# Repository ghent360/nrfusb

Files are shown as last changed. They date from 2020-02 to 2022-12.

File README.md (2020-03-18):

# Theory of operation #

A transmitter and receiver must be programmed with identical 32 bit
radio IDs.  With those IDs, the transmitter and receiver select a set of
23 channels using a pseudorandom number generator.

## Channel Selection ##

23 channels are selected.  Their selection and order is determined as
follows:

The pseudorandom number function is:

```
prn = (prn * 0x0019660D) + 0x3C6EF35F
```

A potential channel is `prn % 125`.  Channels are evaluated in order such that:

* The prn is evaluated once, then modulo 125 to generate a candidate
  channel

* No channel is repeated.  If the candidate channel has already been
  selected, the candidate is discarded.

* No more than a certain number of channels can be chosen from each of
  the different bands.  If a candidate channel would exceed this
  limit, it is discarded.
  * 0-31: 6
  * 32-63: 6
  * 64-95: 6
  * 96-125: 5

## Transmission ##

The transmitter and receiver use the nrf24l01 Enhanced ShockBurst with
the following parameters:

* 5 byte address field, the channel ID mapped into 5 bytes as below
* Dynamic payload length
* 2 byte CRC
* No automatic retransmission
* Auto acknowledgement
* 1Mbps data rate

The transmitter sends a new packet every 20ms, waiting 1ms for an
acknowledgement with data on the same channel.  Each transmitted
packet advances to the next channel in the channel selected list,
wrapping around.

## Reception ##

To initially lock onto a transmitter, the receiver picks a random
channel from the list and listens for 20 channel change times (0.4s).
If no packet is received, it then moves to the next channel in the
list and waits another 20 time periods, continuing this process until
a packet is received.  Once a packet is received it switches to the
following procedure.

In normal reception, immediately after receiving and acknowledging a
packet, the receiver switches to the next channel in the list.  It
waits at least 22ms for the next packet to be received.  If no packet
is received, then the channel is switched to the next one and
listening recommences.  If 5 packets in a row are missed, then the
receiver returns to the initial lock procedure.

## ID selection ##

The ShockBurst address is derived from the 32 bit ID as follows.

1100bbbb bbbbbbbH bbbbbbbH bbbbbbbH bbbbbbH

`b` is a bit from the 32 bit ID.

The `H` bits are selected to be the opposite of whatever the
preceeding bit was.

Rationale: The highest bits are defined to be distinct from the
preamble, which consists of alternating bits.  The H bits are present
to reduce the likelihood that random noise will cause the address to
be identified by the baseband receiver.

## Scheduling ##

The transmitter and receiver have 15 different "slots" to hold
outgoing data.  Each can be configured for a different priority or
transmission rate and each can hold up to 16 bytes of data.

The transmission rate/priority is configured by providing a 32 bit
bitmask denoting in which timeslots this slot should be sent.
Configuring an infeasible set of slots will result in unspecified data
being sent at a lower rate.

A priority of 0 is the default, which signifies that the slot should
not be transmitted.  0xffffffff implies it should be sent every
timeslot.  0x55555555 would be every other timeslot, etc.

The data in a slot will continue to be transmitted at the specified
frequency whether or not it has been updated by the client recently.

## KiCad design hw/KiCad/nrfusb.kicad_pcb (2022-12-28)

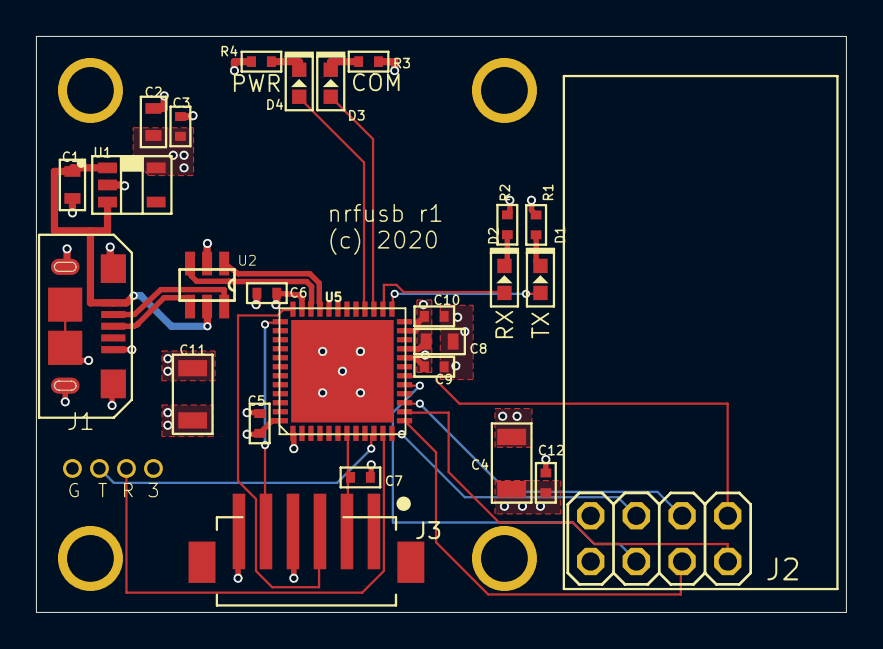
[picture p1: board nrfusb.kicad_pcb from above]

Board: 4 copper layers, 45.0 x 32.0 mm, 34 parts (0 on the bottom side), 26 nets.

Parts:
C1, C2, C8: 1uF; C0603
C3, C5, C6, C7, C9, C10, C12: 0.1uF; C0402
C4, C11: 10uF; C1206
D1, D3: MF-LED-0603-GREEN; LED0603
D2, D4: MF-LED-0603-RED; LED0603
D3V0: PAD24AWG_PAD; 24AWG_PAD
DGND0: PAD24AWG_PAD; 24AWG_PAD
DRX0: PAD24AWG_PAD; 24AWG_PAD
DTX0: PAD24AWG_PAD; 24AWG_PAD
J1: MF-CON-MICROUSB-RIGHT; MICROUSB-RIGHT
J2: 2X04
J3: JST-ZH6SMT_VERT; JST_B6B-ZR-SM4-TF(LF)(SN)
M1, M2, M3, M4: MOUNT; M2.5MOUNT
R1, R2, R3, R4: 220; R0402
U1: MF-REG-SOT235-3.3V-300mA; SOT-23-5
U2: USBLC6-2SC6; SOT23-6L
U5: STM32G474CEU6; QFN50P700X700X60-49N

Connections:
+3V3: C2.P$1, C3.P$1, C4.P$1, C5.P$1, C6.P$1, C8.P$1, C9.P$1, C10.P$1, C11.P$1, C12.P$1, D3V0.P$1, J2.7, J3.6, U1.P$5, U5.1, U5.20, U5.21, U5.23, U5.35, U5.48
DEBUG_RX: DRX0.P$1, U5.11
DEBUG_TX: DTX0.P$1, U5.10
GND: C1.P$2, C2.P$2, C3.P$2, C4.P$2, C5.P$2, C6.P$2, C7.P$2, C8.P$2, C9.P$2, C10.P$2, C11.P$2, C12.P$2, DGND0.P$1, J1.5, J1.S1, J1.S2, J1.S3, J1.S4, J1.S5, J1.S6, J2.8, J3.4, R1.P$1, R2.P$1, R3.P$1, R4.P$1, U1.P$2, U2.2, U5.49
LED_COM: D3.ANODE, U5.27
LED_PWR: D4.ANODE, U5.28
LED_RF_RX: D2.ANODE, U5.26
LED_RF_TX: D1.ANODE, U5.25
unnamed: D1.CATHODE, R1.P$2
unnamed: D2.CATHODE, R2.P$2
unnamed: D3.CATHODE, R3.P$2
unnamed: D4.CATHODE, R4.P$2
NRF_CE: J2.6, U5.17
NRF_CS: J2.5, U5.12
NRF_IRQ: J2.1, U5.18
NRF_MISO: J2.2, U5.14
NRF_MOSI: J2.3, U5.15
NRF_SCK: J2.4, U5.13
NRST: C7.P$1, J3.2, U5.7
SWCLK: J3.5, U5.37
SWDIO: J3.3, U5.36
USB_D_N: J1.2, U2.6
USB_D_P: J1.3, U2.4
USB_F_N: U2.1, U5.33
USB_F_P: U2.3, U5.34
VBUS: C1.P$1, J1.1, U1.P$1, U1.P$3, U2.5

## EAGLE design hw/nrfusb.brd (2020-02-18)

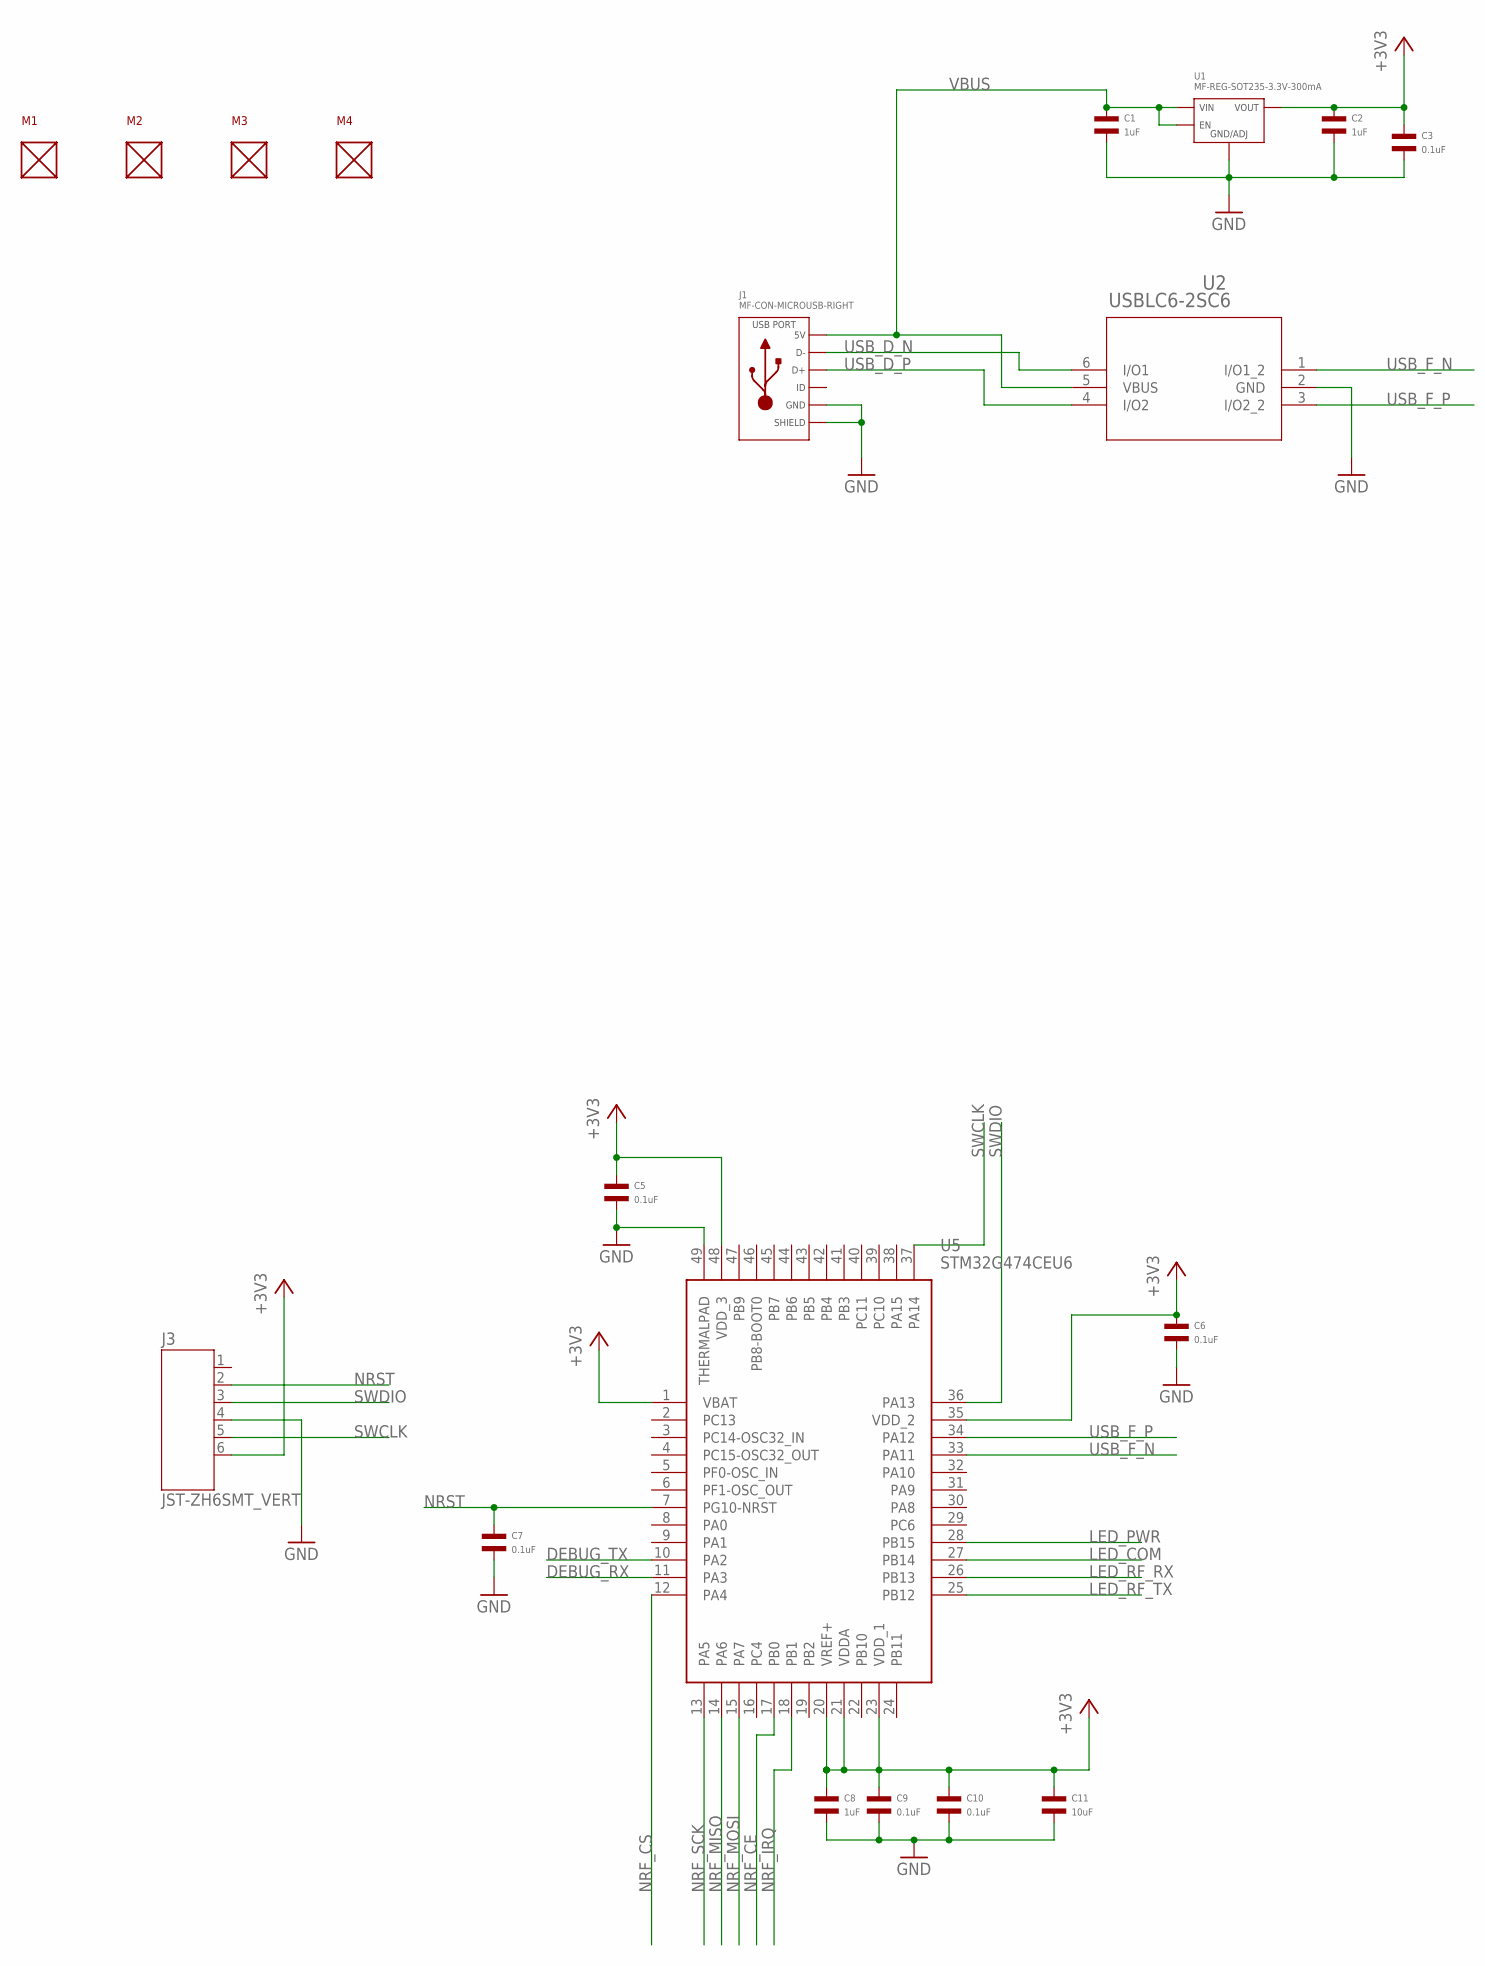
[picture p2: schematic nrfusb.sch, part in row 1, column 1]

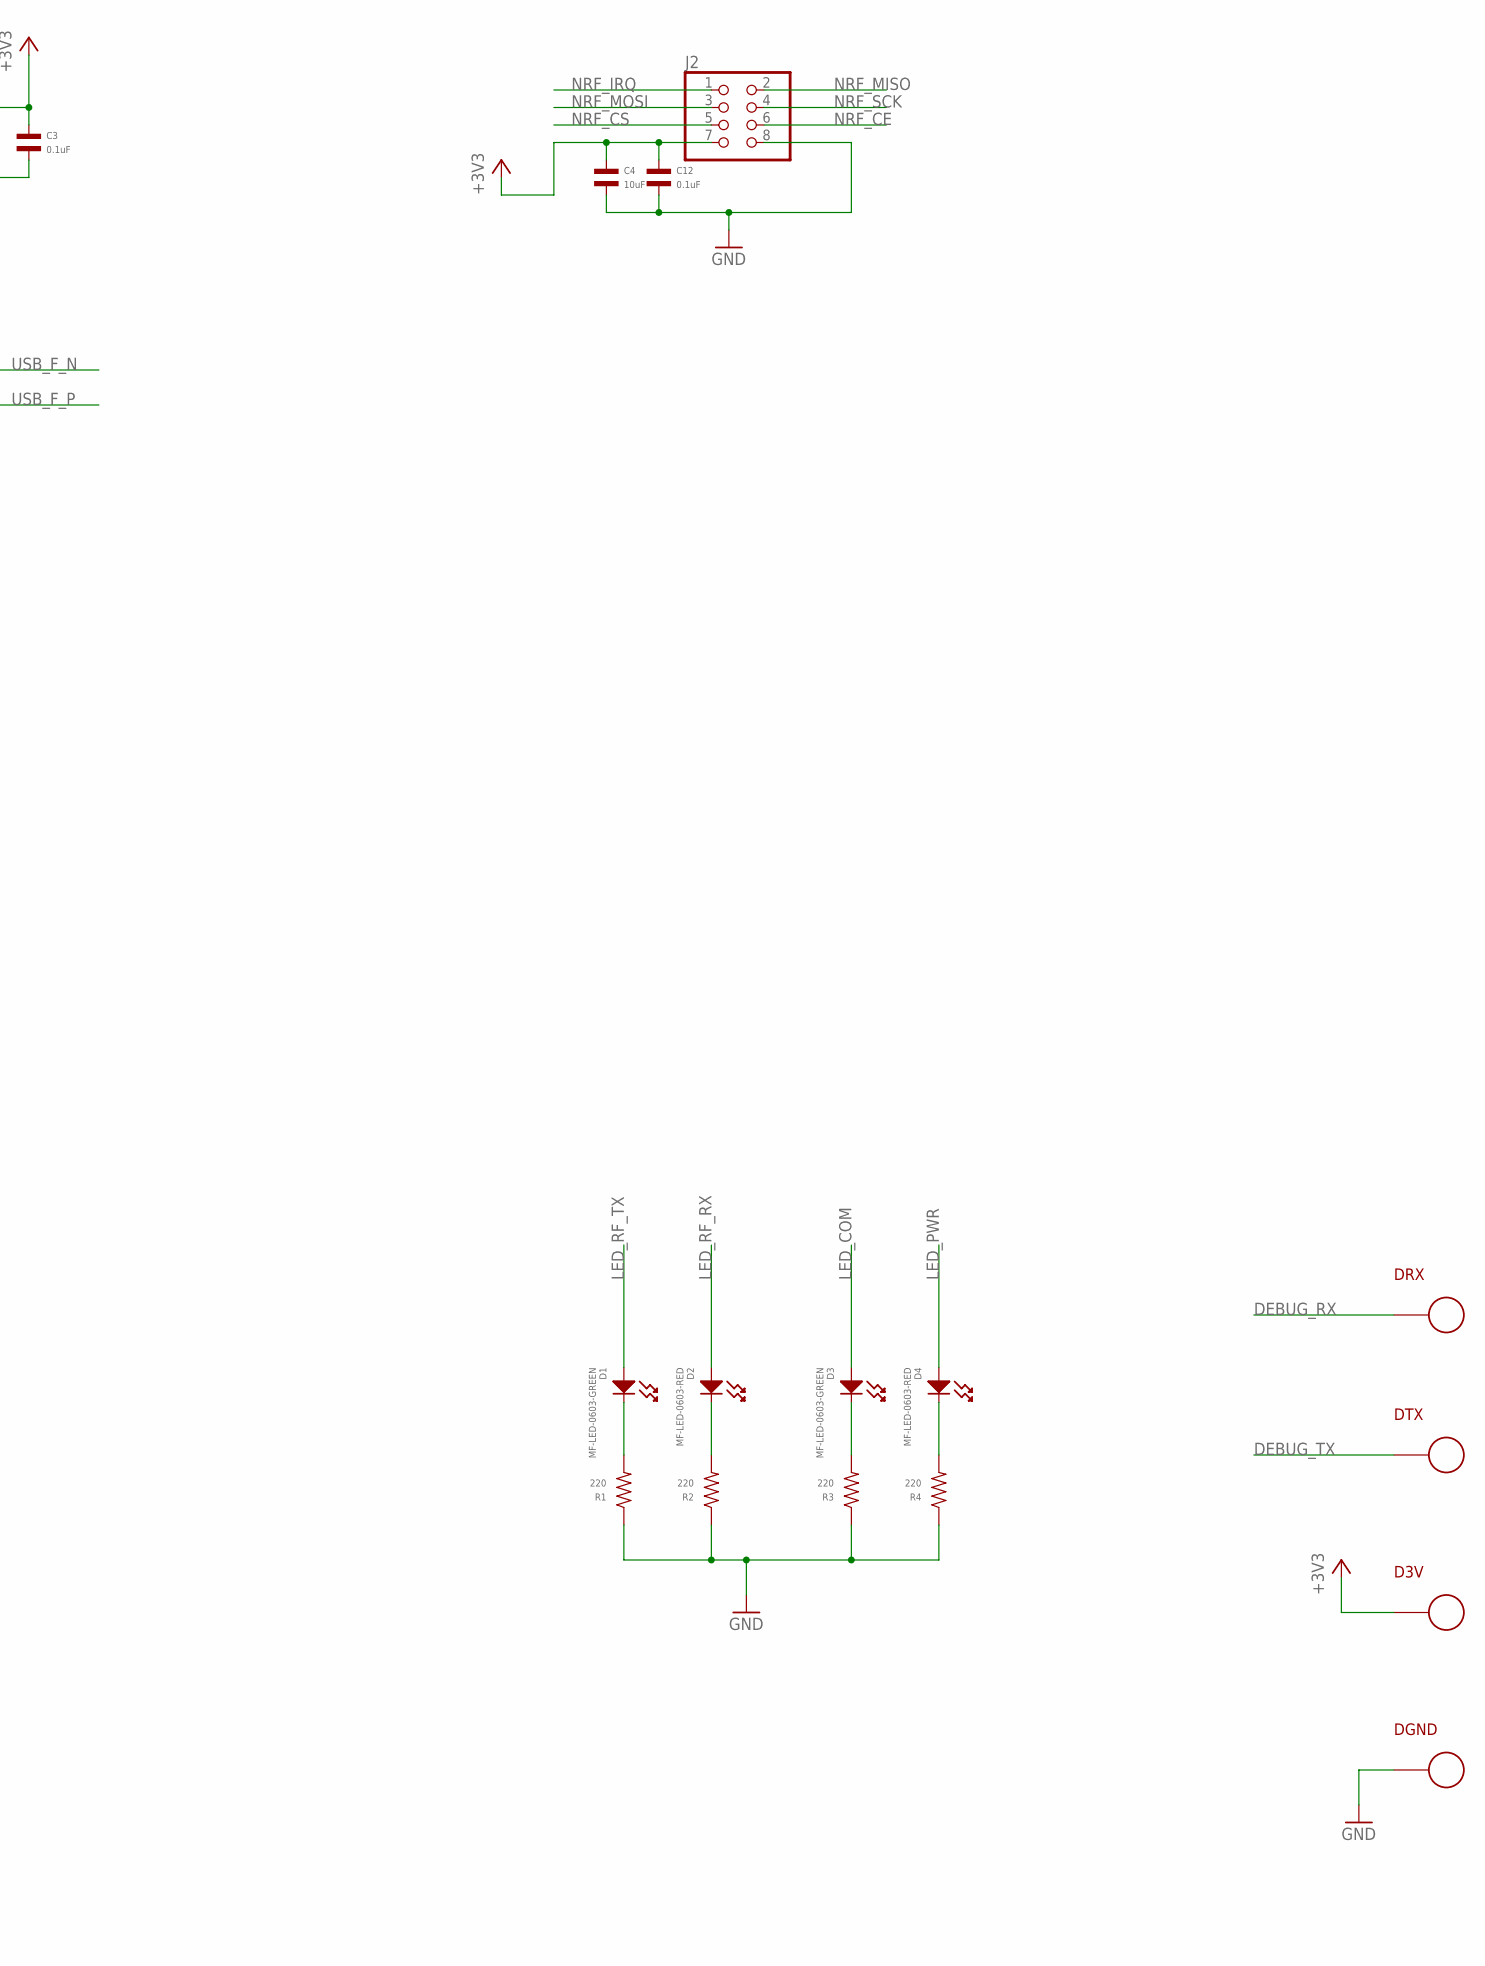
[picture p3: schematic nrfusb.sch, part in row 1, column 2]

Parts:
C1, C2, C8: 1uF; C0603; MPN MF-CAP-0603-1uF
C3, C5, C6, C7, C9, C10, C12: 0.1uF; C0402; MPN MF-CAP-0402-0.1uF
C4, C11: 10uF; C1206; MPN MF-CAP-1206-10uF
D1, D3: MF-LED-0603-GREEN; LED0603
D2, D4: MF-LED-0603-RED; LED0603
D3V: PAD24AWG_PAD; 24AWG_PAD
DGND: PAD24AWG_PAD; 24AWG_PAD
DRX: PAD24AWG_PAD; 24AWG_PAD
DTX: PAD24AWG_PAD; 24AWG_PAD
J1: MF-CON-MICROUSB-RIGHT; MICROUSB-RIGHT
J2: PINHD-2X4; 2X04; MPN 61300821121
J3: JST-ZH6SMT_VERT; JST_B6B-ZR-SM4-TF(LF)(SN); MPN B6B-ZR-SM4-TF(LF)(SN)
M1, M2, M3, M4: MOUNT; M2.5MOUNT
R1, R2, R3, R4: 220; R0402; MPN MF-RES-0402-220
U1: MF-REG-SOT235-3.3V-300mA; SOT-23-5
U2: USBLC6-2SC6; SOT23-6L; MPN USBLC6-2SC6
U5: STM32G474CEU6; QFN50P700X700X60-49N; MPN STM32G474CEU6

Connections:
+3V3: C2.P$1, C3.P$1, C4.P$1, C5.P$1, C6.P$1, C8.P$1, C9.P$1, C10.P$1, C11.P$1, C12.P$1, D3V.P$1, J2.7, J3.6, U1.P$5 (VOUT), U5.1 (VBAT), U5.20 (VREF+), U5.21 (VDDA), U5.23 (VDD_1), U5.35 (VDD_2), U5.48 (VDD_3)
DEBUG_RX: DRX.P$1, U5.11 (PA3)
DEBUG_TX: DTX.P$1, U5.10 (PA2)
GND: C1.P$2, C2.P$2, C3.P$2, C4.P$2, C5.P$2, C6.P$2, C7.P$2, C8.P$2, C9.P$2, C10.P$2, C11.P$2, C12.P$2, DGND.P$1, J1.5 (GND), J1.S1 (SLD), J1.S2 (SLD), J1.S3 (SLD), J1.S4 (SLD), J1.S5 (SLD), J1.S6 (SLD), J2.8, J3.4, R1.P$1, R2.P$1, R3.P$1, R4.P$1, U1.P$2 (GND/ADJ), U2.2 (GND), U5.49 (THERMALPAD)
LED_COM: D3.ANODE, U5.27 (PB14)
LED_PWR: D4.ANODE, U5.28 (PB15)
LED_RF_RX: D2.ANODE, U5.26 (PB13)
LED_RF_TX: D1.ANODE, U5.25 (PB12)
unnamed: D1.CATHODE, R1.P$2
unnamed: D2.CATHODE, R2.P$2
unnamed: D3.CATHODE, R3.P$2
unnamed: D4.CATHODE, R4.P$2
NRF_CE: J2.6, U5.17 (PB0)
NRF_CS: J2.5, U5.12 (PA4)
NRF_IRQ: J2.1, U5.18 (PB1)
NRF_MISO: J2.2, U5.14 (PA6)
NRF_MOSI: J2.3, U5.15 (PA7)
NRF_SCK: J2.4, U5.13 (PA5)
NRST: C7.P$1, J3.2, U5.7 (PG10-NRST)
SWCLK: J3.5, U5.37 (PA14)
SWDIO: J3.3, U5.36 (PA13)
USB_D_N: J1.2 (D-), U2.6 (I/O1)
USB_D_P: J1.3 (D+), U2.4 (I/O2)
USB_F_N: U2.1 (I/O1_2), U5.33 (PA11)
USB_F_P: U2.3 (I/O2_2), U5.34 (PA12)
VBUS: C1.P$1, J1.1 (5V), U1.P$1 (VIN), U1.P$3 (EN), U2.5 (VBUS)

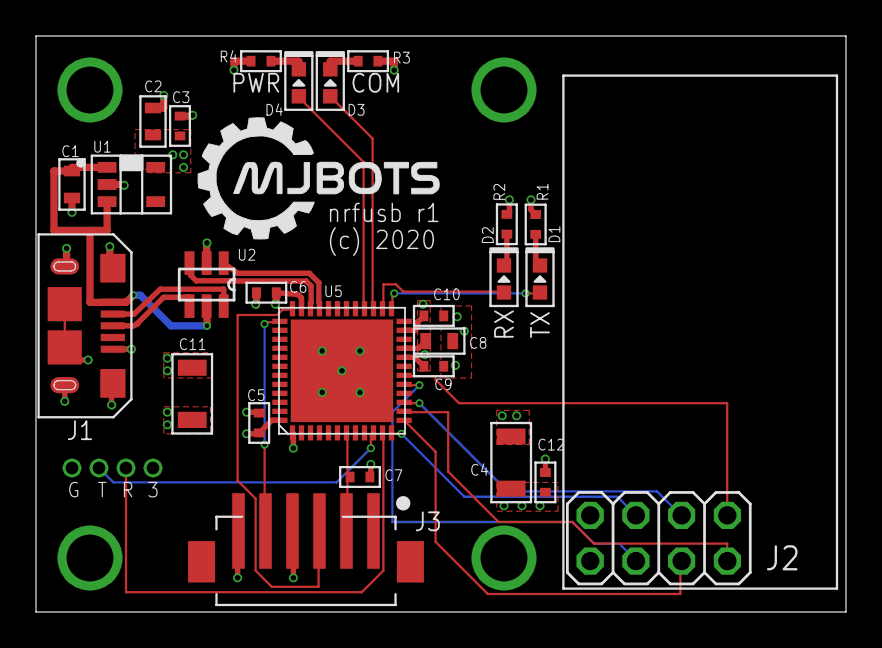
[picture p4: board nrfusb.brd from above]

Board: 4 copper layers, 45.0 x 32.0 mm, 34 parts (0 on the bottom side), 26 nets.

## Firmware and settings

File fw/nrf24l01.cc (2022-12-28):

// Copyright 2020 Josh Pieper, jjp@pobox.com.
//
// Licensed under the Apache License, Version 2.0 (the "License");
// you may not use this file except in compliance with the License.
// You may obtain a copy of the License at
//
//     http://www.apache.org/licenses/LICENSE-2.0
//
// Unless required by applicable law or agreed to in writing, software
// distributed under the License is distributed on an "AS IS" BASIS,
// WITHOUT WARRANTIES OR CONDITIONS OF ANY KIND, either express or implied.
// See the License for the specific language governing permissions and
// limitations under the License.

#include "fw/nrf24l01.h"

#include "mjlib/base/string_span.h"

namespace fw {

Nrf24l01::SpiMaster::SpiMaster(SPI* spi, PinName cs, MillisecondTimer* timer)
    : spi_(spi), cs_(cs, 1), timer_(timer) {
}

uint8_t Nrf24l01::SpiMaster::Command(
    uint8_t command,
    std::string_view data_in,
    mjlib::base::string_span data_out) {
  cs_.write(0);

  // The nrf24l01 has a 38ns CS setup time.  8 nops should get us
  // that for any stm32 frequency.
  asm("nop");
  asm("nop");
  asm("nop");
  asm("nop");
  asm("nop");
  asm("nop");
  asm("nop");
  asm("nop");

  const uint8_t status = spi_->write(command);

  const auto to_transfer =
      std::max<std::size_t>(data_in.size(), data_out.size());
  for (size_t i = 0; i < to_transfer; i++) {
    const uint8_t out_byte = spi_->write(
        (i < data_in.size()) ? data_in[i] : 0);
    if (i < static_cast<std::size_t>(data_out.size())) {
      data_out[i] = out_byte;
    }
  }

  cs_.write(1);

  return status;
}

uint8_t Nrf24l01::SpiMaster::WriteRegister(uint8_t address, std::string_view data) {
  return Command(0x20 + address, data, {});
}

uint8_t Nrf24l01::SpiMaster::WriteRegister(uint8_t address, uint8_t data) {
  return WriteRegister(address, {reinterpret_cast<const char*>(&data), 1});
}

uint8_t Nrf24l01::SpiMaster::ReadRegister(
    uint8_t address, mjlib::base::string_span data) {
  return Command(0x00 + address, {}, data);
}

uint8_t Nrf24l01::SpiMaster::ReadRegister(uint8_t address) {
  uint8_t result = 0;
  ReadRegister(address, {reinterpret_cast<char*>(&result), 1});
  return result;
}

bool Nrf24l01::SpiMaster::VerifyRegister(uint8_t address, std::string_view data) {
  constexpr int kMaxRetries = 2;

  for (int i = 0; i < kMaxRetries; i++) {
    WriteRegister(address, data);
    ReadRegister(address, {buf_, static_cast<ssize_t>(data.size())});
    if (data == std::string_view{buf_, data.size()}) {
      return true;
    }
  }

  // Well, we failed.  Report an error.
  return false;
}

bool Nrf24l01::SpiMaster::VerifyRegister(uint8_t address, uint8_t value) {
  return VerifyRegister(address, {reinterpret_cast<const char*>(&value), 1});
}

Nrf24l01::Nrf24l01(MillisecondTimer* timer, const Options& options)
    : timer_(timer),
      options_(options),
      spi_(options.pins.mosi, options.pins.miso, options.pins.sck),
      nrf_(&spi_, options.pins.cs, timer),
      irq_(options.pins.irq),
      ce_(options.pins.ce, 0) {
  spi_.frequency(10000000);
}

Nrf24l01::~Nrf24l01() {}

void Nrf24l01::Poll() {
  if (irq_.read() == 0) {
    // We have some interrupt to deal with.  Read the status.
    const uint8_t status = nrf_.Command(0xff, {}, {});

    if (status & (1 << 6)) {
      ReadPacket();

      if (is_data_ready_) { rx_overflow_ = true; }
      is_data_ready_ = true;
    }
    if (status & (1 << 4)) {
      // Retransmit count exceeded!
      retransmit_exceeded_++;

      // Flush our TX FIFO.
      nrf_.Command(0xe1, {}, {});
    }

    const uint8_t maybe_to_clear = status & 0x70;
    if (maybe_to_clear) {
      // Yes!
      nrf_.WriteRegister(0x07, maybe_to_clear);
    }
  }
}

void Nrf24l01::PollMillisecond() {
  const auto now = timer_->read_ms();
  // The NRF isn't turned on for 100ms after power up.
  switch (configure_state_) {
    case kPowerOnReset: {
      // While we are in power on reset, leave CE off.
      ce_.write(0);

      // This check can be absolute, because the device only has to
      // do power on reset once.
      if (now < 150) { return; }

      WriteConfig();
      configure_state_ = kEnteringStandby;
      start_entering_standby_ = now;
      return;
    }
    case kEnteringStandby: {
      if ((now - start_entering_standby_) < 2) { return; }

      Configure();
      configure_state_ = kStandby;
      return;
    }
    case kStandby: {
      break;
    }
  }
}

bool Nrf24l01::ready() const {
  return configure_state_ == kStandby;
}

void Nrf24l01::SelectRfChannel(uint8_t channel) {
  MJ_ASSERT(channel < 125);
  if (options_.ptx == 0) {
    // To reliably change the frequency, the receiver needs to be
    // disabled.  It seems to kinda work only for a few limited
    // channels without doing this.
    ce_.write(0);
  }
  VerifyRegister(0x05, channel & 0x7f);  // RF_CH
  if (options_.ptx == 0) {
    ce_.write(1);
  }
}

bool Nrf24l01::is_data_ready() {
  return is_data_ready_;
}

bool Nrf24l01::Read(Packet* packet)  {
  if (!is_data_ready_) {
    packet->size = 0;
    return false;
  }
  *packet = rx_packet_;
  rx_packet_.size = 0;

  // Check to see if there is more remaining.
  const auto status_reg = nrf_.Command(0xff, {}, {});
  is_data_ready_ = ((status_reg >> 1) & 0x07) != 0x07;
  if (is_data_ready_) {
    ReadPacket();
  }

  return true;
}

void Nrf24l01::Transmit(const Packet* packet) {
  MJ_ASSERT(options_.ptx == 1);
  nrf_.Command(0xa0, {&packet->data[0], packet->size}, {});
  // Strobe CE to start this transmit.
  ce_.write(1);
  timer_->wait_us(10);
  ce_.write(0);
}

void Nrf24l01::QueueAck(const Packet* packet) {
  // We always use PPP == 0
  nrf_.Command(0xa8, {&packet->data[0], packet->size}, {});
}

void Nrf24l01::ReadPacket() {
  uint8_t payload_width = 0;
  nrf_.Command(0x60,  // R_RX_PL_WID
               {},
               {reinterpret_cast<char*>(&payload_width), 1});
  if (payload_width > 16) {
    return;
  }
  rx_packet_.size = payload_width;
  if (payload_width) {
    nrf_.Command(0x61, {}, {&rx_packet_.data[0],
            static_cast<ssize_t>(payload_width)});
  }
}

void Nrf24l01::VerifyRegister(uint8_t address, std::string_view data) {
  if (!nrf_.VerifyRegister(address, data) && error_ == 0) {
    // Just report the first error.
    error_ = 0x100 | address;
  }
}

void Nrf24l01::VerifyRegister(uint8_t address, uint8_t value) {
  if (!nrf_.VerifyRegister(address, value) && error_ == 0) {
    error_ = 0x100 | address;
  }
}

void Nrf24l01::WriteConfig() {
  nrf_.WriteRegister(0x00, GetConfig());  // CONFIG
  // Now we need to wait another 1.5ms to enter standby mode for this
  // to take effect.
}
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

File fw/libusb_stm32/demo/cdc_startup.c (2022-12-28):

/* This file is the part of the Lightweight USB device Stack for STM32 microcontrollers
 *
 * Copyright ©2016 Dmitry Filimonchuk <dmitrystu[at]gmail[dot]com>
 *
 * Licensed under the Apache License, Version 2.0 (the "License");
 * you may not use this file except in compliance with the License.
 * You may obtain a copy of the License at
 *   http://www.apache.org/licenses/LICENSE-2.0
 * Unless required by applicable law or agreed to in writing, software
 * distributed under the License is distributed on an "AS IS" BASIS,
 * WITHOUT WARRANTIES OR CONDITIONS OF ANY KIND, either express or implied.
 * See the License for the specific language governing permissions and
 * limitations under the License.
 */

#include "stm32_compat.h"

static void cdc_init_rcc (void) {
#if defined(STM32L0)
    _BST(RCC->APB1ENR, RCC_APB1ENR_PWREN);
    _BMD(PWR->CR, PWR_CR_VOS, PWR_CR_VOS_0);
    _WBC(PWR->CSR, PWR_CSR_VOSF);
    /* set FLASH latency to 1 */
    _BST(FLASH->ACR, FLASH_ACR_LATENCY);
    /* set clock at 32MHz PLL 6/3 HSI */
    _BMD(RCC->CFGR, RCC_CFGR_PLLDIV | RCC_CFGR_PLLMUL | RCC_CFGR_PLLSRC, RCC_CFGR_PLLDIV3 | RCC_CFGR_PLLMUL6);
    _BST(RCC->CR, RCC_CR_HSION);
    _WBS(RCC->CR, RCC_CR_HSIRDY);
    _BST(RCC->CR, RCC_CR_PLLON);
    _WBS(RCC->CR, RCC_CR_PLLRDY);
    /* switch clock to PLL */
    _BMD(RCC->CFGR, RCC_CFGR_SW, RCC_CFGR_SW_PLL);
    _WVL(RCC->CFGR, RCC_CFGR_SWS, RCC_CFGR_SWS_PLL);

#elif defined(STM32L1)
    _BST(RCC->APB1ENR, RCC_APB1ENR_PWREN);
    _BMD(PWR->CR, PWR_CR_VOS, PWR_CR_VOS_0);
    _WBC(PWR->CSR, PWR_CSR_VOSF);
    /* set FLASH latency to 1 */
    _BST(FLASH->ACR, FLASH_ACR_ACC64);
    _BST(FLASH->ACR, FLASH_ACR_LATENCY);
    /* set clock at 32 MHz PLL 6/3 HSI */
    _BMD(RCC->CFGR, RCC_CFGR_PLLDIV | RCC_CFGR_PLLMUL | RCC_CFGR_PLLSRC, RCC_CFGR_PLLDIV3 | RCC_CFGR_PLLMUL6);
    _BST(RCC->CR, RCC_CR_HSION);
    _WBS(RCC->CR, RCC_CR_HSIRDY);
    _BST(RCC->CR, RCC_CR_PLLON);
    _WBS(RCC->CR, RCC_CR_PLLRDY);
    /* switch clock to PLL */
    _BMD(RCC->CFGR, RCC_CFGR_SW, RCC_CFGR_SW_PLL);
    _WVL(RCC->CFGR, RCC_CFGR_SWS, RCC_CFGR_SWS_PLL);

#elif defined(STM32L476xx)
    _BST(RCC->APB1ENR1, RCC_APB1ENR1_PWREN);
    /* Set power Range 1 */
    _BMD(PWR->CR1, PWR_CR1_VOS, PWR_CR1_VOS_0);
    _WBC(PWR->SR2, PWR_SR2_VOSF);
    /* Adjust Flash latency */
    _BMD(FLASH->ACR, FLASH_ACR_LATENCY, FLASH_ACR_LATENCY_2WS);
    /* set clock 48Mhz MSI */
    _BMD(RCC->CR, RCC_CR_MSIRANGE, RCC_CR_MSIRANGE_11 | RCC_CR_MSIRGSEL);
    /* set MSI as 48MHz USB */
    _BMD(RCC->CCIPR, RCC_CCIPR_CLK48SEL, RCC_CCIPR_CLK48SEL_0 | RCC_CCIPR_CLK48SEL_1);
    /* enable GPIOA clock */
    _BST(RCC->AHB2ENR, RCC_AHB2ENR_GPIOAEN);
    /* set GP11 and GP12 as USB data pins AF10 */
    _BST(GPIOA->AFR[1], (0x0A << 12) | (0x0A << 16));
    _BMD(GPIOA->MODER, (0x03 << 22) | (0x03 << 24), (0x02 << 22) | (0x02 << 24));

#elif defined(STM32F103x6)
    /* set flash latency 1WS */
    _BMD(FLASH->ACR, FLASH_ACR_LATENCY, FLASH_ACR_LATENCY_1);
    /* use PLL 48MHz clock from 8Mhz HSI */
    _BMD(RCC->CFGR,
         RCC_CFGR_PLLMULL | RCC_CFGR_PLLSRC | RCC_CFGR_USBPRE,
         RCC_CFGR_PLLMULL12 | RCC_CFGR_USBPRE);
    _BST(RCC->CR, RCC_CR_PLLON);
    _WBS(RCC->CR, RCC_CR_PLLRDY);
    /* switch to PLL */
    _BMD(RCC->CFGR, RCC_CFGR_SW, RCC_CFGR_SW_PLL);
    _WVL(RCC->CFGR, RCC_CFGR_SWS, RCC_CFGR_SWS_PLL);

#elif defined(STM32F303xE)
    /* set flash latency 1WS */
    _BMD(FLASH->ACR, FLASH_ACR_LATENCY, FLASH_ACR_LATENCY_1);
    /* use PLL 48MHz clock from 8Mhz HSI */
    _BMD(RCC->CFGR,
         RCC_CFGR_PLLMUL | RCC_CFGR_PLLSRC | RCC_CFGR_USBPRE,
         RCC_CFGR_PLLMUL12 | RCC_CFGR_USBPRE);
    _BST(RCC->CR, RCC_CR_PLLON);
    _WBS(RCC->CR, RCC_CR_PLLRDY);
    /* switch to PLL */
    _BMD(RCC->CFGR, RCC_CFGR_SW, RCC_CFGR_SW_PLL);
    _WVL(RCC->CFGR, RCC_CFGR_SWS, RCC_CFGR_SWS_PLL);

#elif defined(STM32F303xC)
    /* set flash latency 1WS */
    _BMD(FLASH->ACR, FLASH_ACR_LATENCY, FLASH_ACR_LATENCY_1);
    /* use PLL 48MHz clock from 8Mhz HSI */
    _BMD(RCC->CFGR,
         RCC_CFGR_PLLMUL | RCC_CFGR_PLLSRC | RCC_CFGR_USBPRE,
         RCC_CFGR_PLLMUL12 | RCC_CFGR_USBPRE);
    _BST(RCC->CR, RCC_CR_PLLON);
    _WBS(RCC->CR, RCC_CR_PLLRDY);
    /* switch to PLL */
    _BMD(RCC->CFGR, RCC_CFGR_SW, RCC_CFGR_SW_PLL);
    _WVL(RCC->CFGR, RCC_CFGR_SWS, RCC_CFGR_SWS_PLL);
    
    _BST(RCC->AHBENR, RCC_AHBENR_GPIOAEN);
    _BST(GPIOA->AFR[1], (0x0E << 12) | (0x0E << 16));
    _BMD(GPIOA->MODER, (0x03 << 22) | (0x03 << 24), (0x02 << 22) | (0x02 << 24));

#elif defined(STM32F373xC)
    /* set flash latency 1WS */
    _BMD(FLASH->ACR, FLASH_ACR_LATENCY, FLASH_ACR_LATENCY_1);
    _BMD(RCC->CFGR,
         RCC_CFGR_PLLMUL | RCC_CFGR_PLLSRC | RCC_CFGR_USBPRE | RCC_CFGR_PPRE1,
         RCC_CFGR_PLLMUL12  | RCC_CFGR_USBPRE | RCC_CFGR_PPRE1_DIV2);
    _BST(RCC->CR, RCC_CR_PLLON);
    _WBS(RCC->CR, RCC_CR_PLLRDY);
    /* switch to PLL */
    _BMD(RCC->CFGR, RCC_CFGR_SW, RCC_CFGR_SW_PLL);
    _WVL(RCC->CFGR, RCC_CFGR_SWS, RCC_CFGR_SWS_PLL);

    /* Enabling USB PA11 PA12 AF 0x0E.
     * This is still undocumented in the 7th!! revision of the datasheet.
     * Thank you, mo***rs from ST for extra 5 hrs of debugging.
     */
    _BST(RCC->AHBENR, RCC_AHBENR_GPIOAEN);
    _BST(GPIOA->AFR[1], (0x0E << 12) | (0x0E << 16));
    _BMD(GPIOA->MODER, (0x03 << 22) | (0x03 << 24), (0x02 << 22) | (0x02 << 24)); // MCO
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

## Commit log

2019-10-08 Initialize with a fork of fdcanusb
    [nrfusb.brd, nrfusb.sch]
2019-10-08 Nominally complete board and schematic
    [nrfusb.brd, nrfusb.sch]
2020-02-18 Update with correct stm32 pinout
    [nrfusb.brd, nrfusb.sch]
2020-02-18 Fine tweak silks
    [nrfusb.brd]
2020-03-07 Configure the nrf on power up
2020-03-16 Refactor pin configuration to enable direct pass through
2020-03-17 Beginnings of the slot protocol implementation
2020-03-17 First draft of an interface and misc bug fixes
    This currently has raw vs. slot selected at compile time. It also
    doesn't work properly yet, but does transmit "something".
    [nrf24l01.cc]
2020-03-18 Fix enough bugs to get sending and receiving working
    [nrf24l01.cc]
2020-03-18 Set SPI frequency to 10MHz
2020-03-18 Use the correct frequency for the millisecond timer
2020-03-18 No longer die for errors
    [nrf24l01.cc]
2020-03-18 Make parsing of slots greater than 0 actually work
2020-03-18 Get priority selection working and fix other bugs
    [nrf24l01.cc]
2022-12-28 Update libusb_stm32 to the latest version. Make code compile for STM32F4.
2022-12-28 Fix issues with no NRF module connected.
    [nrf24l01.cc]
2022-12-28 Add file to initialize the USB pins on STM32F4.
2022-12-28 Add KiCAD schematics and PCB, fix clock source for the F4 board.
    [nrfusb.kicad_pcb]
2022-12-28 Switch to my copy of rules_mbed.
2022-12-28 Fix STM32F1 compile issues. Sadly the binary is too big for the bluepill.

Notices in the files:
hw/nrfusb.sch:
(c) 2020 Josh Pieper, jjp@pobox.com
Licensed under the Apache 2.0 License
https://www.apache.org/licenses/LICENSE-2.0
